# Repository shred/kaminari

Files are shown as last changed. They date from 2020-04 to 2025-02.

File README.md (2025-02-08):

# Kaminari

This is an ESP8266 and AS3935 based Franklin Lightning Detector. It connects to a WiFi network, and offers a JSON web service for detected lightnings.

**WARNING: This project is for educational purposes only.** This is just a toy. It is not intended to be used as an early warning indicator for lightning related storms. It does not guarantee accuracy or predict exact strike locations. It it not a replacement for a professional lightning detector. Again: **This is just a toy.**

## Features

* Small size and low power consumption
* Can be read out and configured via HTTP web service and JSON
* Lightnings can be reported via MQTT
* Optional RGBW LED for showing the system status and detected lightnings
* Self-calibrating detector
* Permanent automatic noise floor level adjustment

## Building and Installation

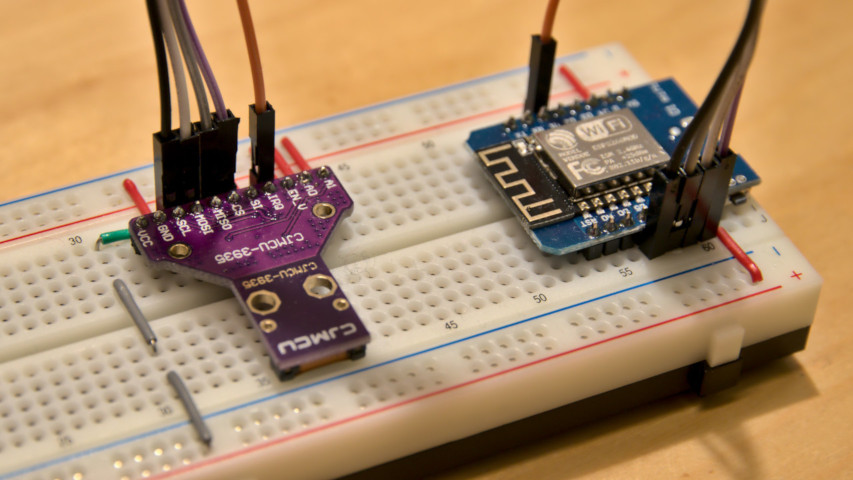
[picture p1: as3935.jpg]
Prototype


### Hardware

You need:

- An **ESP8266** module. You can use any brand, as long as it provides a regulated 3.3 V power source, and exposes the SPI interface and GPIO 5.
- An **AS3935** Franklin Lightning Detector module. Again, no special brand is required, as long as the SPI interface is exposed.

The lightning detector is connected like this:

- Vcc → 3.3 V power output of the ESP board
- SCL → CLK (IO14)
- MOSI → MOSI (IO13)
- MISO → MISO (IO12)
- CS → CS (IO15)
- IRQ → IO5

All other terminals of the detector are connected to GND of the ESP board.

Optionally, a single **SK6812** RGBW LED can be added as a status LED. It is must be powered by 5 V, and its data input is directly connected to IO4.

No other components are required.

To fully understand the functionality of the lightning detector, please read the [AS3935 datasheet](https://www.sciosense.com/wp-content/uploads/documents/AS3935-Data-Sheet.pdf).

### Important Notes

- The ESP8266's WiFi is disturbing the AS3935 detector, and reducing the quality of lightning detection up to a point where lightnings cannot be detected at all. **Make sure there is sufficient space between both boards!** There should be at least 10 cm between the WiFi antenna and the detector coil. The more space, the better.

* Some manufacturers of the lightning detector print a calibration value on the package. As Kaminari calibrates the detector automatically, the calibration value is not needed.

* Some AS3935 boards are equipped with non-standard parts in the antenna RC, and thus cannot be tuned to the recommended frequency of 500 kHz. If you're lucky, it is still within the required tolerance of ±3.5%. Those boards can be used, but may give inferior results. It is not a fault of Kaminari if the exact frequency is missed. (I got multiple reports about CJMCU boards having this issue, and can confirm it with my own board of this brand.)

### Firmware

To build the firmware, you need to install the [Arduino IDE](https://www.arduino.cc/en/Main/Software). After installation, just open the `kaminari.ino` file.

### Dependencies

Please make sure these libraries are installed in the Library Manager of the Arduino IDE:

* [Arduino on ESP8266](https://github.com/esp8266/Arduino) (via Board Manager)
* [ArduinoJson](https://arduinojson.org/)
* [Adafruit NeoPixel](https://github.com/adafruit/Adafruit_NeoPixel)
* [EEPROM_Rotate](https://github.com/xoseperez/eeprom_rotate)
* [PubSubClient](https://github.com/knolleary/pubsubclient)

### Configuration

Before you build the project for the first time, please copy the `myWiFi.h.example` file to `myWiFi.h`, and adapt it to your needs:

- `MY_SSID`: The SSID of your WLAN to connect to
- `MY_PSK`: The password of your WLAN
- `MY_APIKEY`: Your API key for endpoint calls that change the state of the detector. You can set a random, password-like word here.
- `MY_MDNS_NAME`: Your preferred mDNS name. Just use the default value `kaminari` if you don't know what to use here.

To send lightning events via MQTT, these additional options need to be configured:

- `MY_MQTT_ENABLED`: This line needs to be commented in to activate MQTT support. MQTT is disabled by default.
- `MY_MQTT_SERVER_HOST`: Host name of the MQTT server.
- `MY_MQTT_SERVER_PORT`: Port of the MQTT server (default is 1883).
- `MY_MQTT_USER`: MQTT authentication user name
- `MY_MQTT_PASSWORD`: MQTT authentication password
- `MY_MQTT_TOPIC`: MQTT topic to be used
- `MY_MQTT_RETAIN`: `true` if messages shall be retained. Default is `false`.

### Installation

Now you can build the project in ArduinoIDE.

After that, connect your ESP8266 via USB. In the _Tools_ menu, please set all parameters so you can upload the sketch to your ESP8266. The settings depend on the brand of your module and on your computer's operating system, so there are no generic settings that can be recommended here.

When everything is completed, upload the sketch to your module. That's all.

You can open the _Serial Monitor_ to read some debug output of Kaminari as it starts up. You will find the WiFi status, the IP address, and the calibration results there.

### Connection

There is a small web server running in Kaminari. You can connect to it by pointing your browser to the IP address (e.g. http://192.168.1.23/status).

Kaminari uses mDNS. If your operating system supports it, you can also connect to the sensor via http://kaminari.local/status (or whatever mDNS name you have used in your `myWiFi.h` file).

## Endpoints

Kaminari offers a set of endpoints. Some endpoints are read-only. Other endpoints change the state of the detector, and thus require the API key to be passed in via `X-API-Key` header or `api_key` URL parameter. For the sake of simplicity, all requests are `GET` requests, even those that change the state of the detector.

### `/status`

Returns the current status of the detector as JSON structure. This is an example result:

```
{
    "lightnings": [
        {
            "age": 34,
            "distance": 12,
            "energy": 38123
        }
    ],
    "distance": null,
    "energy": 0,
    "noiseFloorLevel": 146,
    "disturbersPerMinute": 81,
    "watchdogThreshold": 1,
    "wifiSignalStrength": -55
}
```

This is the meaning of the individual properties:

- `lightnings`: An array of detected lightnings. It contains the `age` of the event (in seconds), the estimated `distance` of the lightning (in kilometres) and the lightning `energy` (no physical unit). Kaminari stores up to 64 lightning events, and returns them in antichronological order. When a 65th event is recorded, the oldest record will automatically be removed from the list. This array is empty if no lightnings have been detected yet.
- `distance`: General distance of the storm, in kilometres. `null` means that the storm is out of range, while `1` means that the storm is overhead. May also contain values caused by disturbers. For debugging purposes only, may be removed in a future version.
- `energy`: General energy of detected lightnings, with no physical unit. May also contain values caused by disturbers. For debugging purposes only, may be removed in a future version.
- `noiseFloorLevel`: Current noise floor level, in µVrms. Kaminari raises or lowers the level automatically, depending on the level of environment radio noises.
- `disturbersPerMinute`: Number of detected disturbers per minute. The value should be as low as possible for best results. Higher values mean that the detector is receiving a lot of disturbing radio noises.
- `watchdogThreshold`: Current watchdog threshold. Range is between 0 and 10. Higher values mean lower sensibility against disturbers, but also lower sensibility against very far lightning events.
- `wifiSignalStrength`: Current WiFi received signal strength, in dBm.

### `/settings`

Returns the current settings of the detector as JSON structure, for example:

```
{
    "tuning": 500135,
    "noiseFloorLevel": 146,
    "outdoorMode": false,
    "watchdogThreshold": 2,
    "minimumNumberOfLightning": 1,
    "spikeRejection": 2,
    "statusLed": true,
    "blueBrightness": 48,
    "disturberBrightness": 100
}
```

- `tuning`: The tuning of the internal antenna, in Hz. Should be around 500 kHz, with a tolerance of ±3.5%.
- `noiseFloorLevel`: Current noise floor level, in µVrms.
- `outdoorMode`: `true` if the detector is switched to outdoor mode. In outdoor mode, a higher noise floor level voltage is used for suppressing disturbers. If the LED is blinking blue, you can try to enable the outdoor mode to make the device less sensitive for disturbers.
- `watchdogThreshold`: Current watchdog threshold, see AS3935 datasheet.
- `minimumNumberOfLightning`: Minimum number of lightnings until a lightning detected event is triggered.
- `spikeRejection`: Current spike rejection, see AS3935 datasheet.
- `statusLed`: If `true`, the status LED displays signal quality and detected lightnings. If `false`, the status LED will only display important system states (WLAN disconnected, calibration in progress) and is turned off otherwise.
- `blueBrightness`: Maximum brightness of the blue LED indicating the noise floor level.
- `disturberBrightness`: Brightness of the LED when a disturber is detected.

### `/update`

This endpoint permits to change the settings. Settings to be changed are passed as URL parameter:

- `outdoorMode`: Enable or disable the outdoor mode.
- `watchdogThreshold`: Watchdog threshold, between 0 and 10, see AS3935 datasheet. Higher numbers give better robustness against disturber signals, but a lower lightning detection rate.
- `minimumNumberOfLightning`: Minimum number of lightnings until a lightning detected event is triggered. Only 1, 5, 9, and 16 are permitted, other values will be ignored.
- `spikeRejection`: Spike rejection, between 0 and 11, see AS3935 datasheet. Higher numbers give better robustness against disturber signals, but a lower lightning detection rate.
- `statusLed`: Change the status LED operation.
- `blueBrightness`: Maximum brightness of the blue LED indicating the noise floor level, between 0 and 255. 0 turns the constant blue light off, while lightnings, disturbers, and system states are still indicated.
- `disturberBrightness`: Brightness of the LED when a disturber is detected, between 0 and 255. 0 to turn off disturber indication.

The changes are permanently stored and will still be effective after Kaminari had been powered off and on.

Other settings are managed by Kaminari and cannot be changed externally.

The API key is required for this call.

### `/calibrate`

This endpoint forces a new calibration of the internal oscillators. The calibration takes approximately 5 seconds. The calibrated antenna tuning is returned. It should be around 500 kHz.

The API key is required for this call.

### `/clear`

This endpoint clears the list of detected lightnings, the age of the last detected disturber, and the counter of disturbers per minute.

The API key is required for this call.

### `/reset`

This endpoint resets the detector chip. May be useful if the detector cracks up or behaves strangely. This call also includes a calibration and resetting the statistics.

The API key is required for this call.

## Status LED

An optional RGBW LED is showing the current status of the device:

- **constant yellow**: The antenna is being calibrated. This takes approximately 5 seconds.
- **blinking red**: The WLAN connection is lost, and the device is currently trying to reconnect.
- **constant blue**: The device is in normal operation mode. The brightness of the blue color is an indicator for the current noise floor level. Darker blue indicates a lower noise floor level, which should be preferred. The maximum brightness can be changed via the `/update` endpoint.
- **blinking blue**: The maximum noise floor level has been reached. Background noise is too high. You should find a different place for your detector, or enable the outdoor mode. Try to keep it away from electronic devices, especially bluetooth devices, mobile phones or microwaves.
- **white flash**: A lightning has been detected.
- **fading red, yellow or green tints**: Indicates the estimated distance (color) and the intensity of the lightning (brightness). Green indicates that the storm is about 40 km away. Red indicates that the storm is overhead. The hue of other colors represent distances between.
- **fading pink/red tints** without prior white flash: A disturber has been detected.

## MQTT events

If MQTT support is enabled, Kaminari will publish a message on every detected lightning event. The payload is a JSON structure:

```
{
    "energy": 0,
    "distance": null,
    "tuning": 500135,
    "noiseFloorLevel": 146,
    "disturbersPerMinute": 2,
    "watchdogThreshold": 1,
    "wifiSignalStrength": -55
}
```

This is the meaning of the individual properties:

- `energy`: Estimated energy of the detected lightning (no physical unit). May be `null` if a disturber was detected.
- `distance`: Estimated distance of the lightning, in kilometres. May be `null` if the storm is out of range. `1` means that the storm is overhead.
- `tuning`: The tuning of the internal antenna, in Hz. Should be around 500 kHz, with a tolerance of ±3.5%.
- `noiseFloorLevel`: Current noise floor level, in µVrms. Kaminari raises or lowers the level automatically, depending on the level of environment radio noises. This value gives a hint about signal quality.
- `disturbersPerMinute`: Number of detected disturbers per minute. The value should be as low as possible for best results. Higher values mean that the detector is receiving a lot of disturbing radio noises. This value gives a hint about signal quality.
- `watchdogThreshold`: Current watchdog threshold. Range is between 0 and 10. Higher values mean lower sensibility against disturbers, but also lower sensibility against very far lightning events. This value gives a hint about signal quality.
- `wifiSignalStrength`: Current WiFi received signal strength, in dBm.

## Data Recording

You can frequently poll the `/status` endpoint for lightnings and other sensor values. This can be done either manually or automated.

[Geordi](https://geordi.shredzone.org) is a tool that frequently polls the status and stores the samples in a Postgresql database. It supports Kaminari directly. [Grafana](https://grafana.com/) can be used for visualising the results.

## FAQ

- **Does this detector warn me in time if…**

  No.

  Seriously, this is just a toy, and only meant for experimenting and having fun. Never trust your life and other valuable stuff on it.

- **How can I test it?**

  The manufacturer sells a [demo kit](https://www.sciosense.com/products/wireless-sensor-nodes/demo-kit-for-as3935/) that also contains a "lightning emulator", but the least expensive way is to wait for an actual thunderstorm.

  You can also increase sensitivity by reducing `watchdogThreshold` and `spikeRejection`, and then try to simulate lightnings by switching a light switch. I could also simulate lightnings by using a bluetooth mouse or a mobile phone close to the sensor.

- **I get a lot of false lightning events.**

  You can experiment with the `watchdogThreshold`, `spikeRejection` and `minimumNumberOfLightning` settings. There is not much more that can be done though.

- **Lightnings are not detected.**

  Your detector might be located in a place with too many radio noises. Try to find a different place, far away from radio sources (like smartphones or bluetooth devices). You can also try to reduce `watchdogThreshold`, `spikeRejection` or `minimumNumberOfLightning`.

  The ESP8266 WiFi is a strong disturber. Try to give more space between the WiFi antenna and the detector coil, in order to reduce disturbers.

  Lightnings are only detected in a radius of up to 40 km. However, lightnings are poorer detected with increasing distance.

- **I get a lot of disturber indications.**

  Try to find a place with less radio disturbers, and experiment with the `watchdogThreshold` and `spikeRejection` settings. If the disturber indications are annoying you, you can also set `disturberBrightness` to 0.

- **I'd to write my own lightning detector firmware.**

  The `AS3935.cpp` and `AS3935.h` files in this project provide a generic driver class for the AS3935 sensor chip. You can use it in your own project, as long as you won't remove the copyright header and respect the terms of our license.

- **Are kits or assembled devices available?**

  No, at least not that I am aware of.

## Contribute

* Fork the [Source code at Codeberg](https://codeberg.org/shred/kaminari). Feel free to send pull requests.
* Found a bug? [File a bug report!](https://codeberg.org/shred/kaminari/issues) However, please don't file complaints about a poor accuracy or false detections. Remember that this is a toy and not a professional lightning detector.

## License

_Kaminari_ is open source software. The source code is distributed under the terms of [GNU General Public License (GPLv3+)](https://www.gnu.org/licenses/gpl-3.0.en.html).

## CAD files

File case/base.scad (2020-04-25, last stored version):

/*
 * Kaminari
 *
 * Copyright (C) 2020 Richard "Shred" Körber
 *   https://github.com/shred/kaminari
 *
 * This program is free software: you can redistribute it and/or modify
 * it under the terms of the GNU General Public License as published by
 * the Free Software Foundation, either version 3 of the License, or
 * (at your option) any later version.
 *
 * This program is distributed in the hope that it will be useful,
 * but WITHOUT ANY WARRANTY; without even the implied warranty of
 * MERCHANTABILITY or FITNESS FOR A PARTICULAR PURPOSE.  See the
 * GNU General Public License for more details.
 */

use <kaminari.scad>
lower();

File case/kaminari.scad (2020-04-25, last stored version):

/*
 * Kaminari
 *
 * Copyright (C) 2020 Richard "Shred" Körber
 *   https://github.com/shred/kaminari
 *
 * This program is free software: you can redistribute it and/or modify
 * it under the terms of the GNU General Public License as published by
 * the Free Software Foundation, either version 3 of the License, or
 * (at your option) any later version.
 *
 * This program is distributed in the hope that it will be useful,
 * but WITHOUT ANY WARRANTY; without even the implied warranty of
 * MERCHANTABILITY or FITNESS FOR A PARTICULAR PURPOSE.  See the
 * GNU General Public License for more details.
 */

basesize = 60;
tipheight = 40;
wall = 1.5;

mount_distance = 40;
mount_diameter = 7;
mount_screw_diameter = 3;
mount_screw_length = 10;
mount_head_depth = 2;
mount_head_diam = 5.8;

usb_width = 11;
usb_height = 7;

module pyramid(size) {
    height = size/2 * sqrt(3);
    polyhedron(
        points=[
            [ size/2,  size/2, 0     ],
            [ size/2, -size/2, 0     ],
            [-size/2, -size/2, 0     ],
            [-size/2,  size/2, 0     ],
            [      0,       0, height]
        ],
        faces=[
            [0,1,4],
            [1,2,4],
            [2,3,4],
            [3,0,4],
            [1,0,3], [2,1,3]
        ]
    );
}

module led() {
    color("silver") cylinder(d=10, h=1.3);
    color("white") translate([0, 0, 1.3 + (2.8-1.3)/2]) cube([5, 5, 2.8-1.3], center=true);
}

module detector() {
    translate([-28.4/2, -30.1/2, 0]) {
        color("purple") difference() {
            linear_extrude(height=2.4) {
                polygon([[0, 0], [28.4, 0], [28.4, 9.2], [20.25, 15.1], [20.25, 30.1], [8.15, 30.1], [8.15, 15.1], [0, 9.2], [0, 0]]);
            }
            translate([ 8.15 + 3/2 + 1, 21, -1]) cylinder(d=2.95, h=4);
            translate([20.25 - 3/2 - 1, 21, -1]) cylinder(d=2.95, h=4);
        }
        color("darkslategrey") translate([8.15, 30.1-3.2, 2.4]) cube([12.1, 3.2, 1.8]);
        color("black") translate([0, 0, -1]) cube([28.4, 2.5, 11.4]);
    }
}

module mcu() {
    translate([-25.8/2, -34/2, 8]) {
        color("royalblue") cube([25.8, 34, 1.3]);
        color("silver") translate([(25.8-12)/2, 12, 1.3]) cube([12, 15, 3.2]);
        color("black") translate([0, 0, -2]) cube([25.8, 28, 2]);
        color("silver") translate([(25.8-7.8)/2, -0.1, -1.9]) cube([7.8, 7, 1.9]);
        color("black") translate([0, 7.4, -8]) cube([2.5, 21, 8]);
        color("black") translate([25.8-2.5, 7.4, -8]) cube([2.5, 21, 8]);
    }
}

module stripe(dim) {
    translate([dim[1]/2, 0, 0]) cylinder(d=dim[1], h=dim[2]);
    translate([dim[1]/2, -dim[1]/2, 0]) cube([dim[0] - dim[1], dim[1], dim[2]]);
    translate([dim[0] - dim[1]/2, 0, 0]) cylinder(d=dim[1], h=dim[2]);
}

module mountBar(height) {
    difference() {
        cylinder(d = mount_diameter, h = height);
        cylinder(d = mount_screw_diameter, h = mount_screw_length, $fn = 5);
    }
}

module upper() {
    difference() {
        intersection() {
            pyramid(basesize);
            ph =  basesize/2 * sqrt(3);
            translate([0, 0, ph/2 - 1]) cube([basesize, basesize, ph], center=true);
        }
        pyramid(basesize - wall*2);
        translate([(-usb_width)/2, (usb_height-7)/2-20, 8]) rotate([90, 0, 0]) stripe([usb_width, usb_height, 10]);
    }

    intersection() {
        union() {
            translate([ mount_distance/2,  mount_distance/2, wall*2]) mountBar(basesize);
            translate([ mount_distance/2, -mount_distance/2, wall*2]) mountBar(basesize);
            translate([-mount_distance/2,  mount_distance/2, wall*2]) mountBar(basesize);
            translate([-mount_distance/2, -mount_distance/2, wall*2]) mountBar(basesize);
        }
        pyramid(basesize);
    }
}

module middle_led() {
    difference() {
        translate([-10, -10, 0]) cube([20, 20, 3.5]);
        translate([0, 0, 1]) cylinder(d=10.5, h=4);
        rotate([0, 0, -180]) translate([-4.3, -2, -.1]) stripe([8.6, 5, 3.2]);
    }
}

module lower_detector() {
    translate([-11.5, -basesize/2 - 15, 0]) cube([4, basesize, 20]);
}

module middle() {
    intersection() {
        difference() {
            union() {
                // LED holder
                translate([0, 0, 35]) middle_led();
                translate([-basesize/2, -basesize/2, 22]) cube([basesize, 30, 13]);
            }
            translate([ 3.5, -6, 21.9]) cylinder(d=3, h=12, $fn=5);
            translate([-3.5, -6, 21.9]) cylinder(d=3, h=12, $fn=5);
        }
        pyramid(basesize - wall*2);
    }
}

module basePlate() {
    difference() {
        union() {
            translate([0, 0, wall/2]) cube([basesize, basesize, wall], center=true);
            translate([ mount_distance/2,  mount_distance/2, 0]) cylinder(d = mount_diameter, h = wall*2);
            translate([ mount_distance/2, -mount_distance/2, 0]) cylinder(d = mount_diameter, h = wall*2);
            translate([-mount_distance/2,  mount_distance/2, 0]) cylinder(d = mount_diameter, h = wall*2);
            translate([-mount_distance/2, -mount_distance/2, 0]) cylinder(d = mount_diameter, h = wall*2);
        }

        translate([ mount_distance/2,  mount_distance/2, 0]) cylinder(d = mount_screw_diameter, h = mount_screw_length);
        translate([ mount_distance/2, -mount_distance/2, 0]) cylinder(d = mount_screw_diameter, h = mount_screw_length);
        translate([-mount_distance/2,  mount_distance/2, 0]) cylinder(d = mount_screw_diameter, h = mount_screw_length);
        translate([-mount_distance/2, -mount_distance/2, 0]) cylinder(d = mount_screw_diameter, h = mount_screw_length);

        translate([ mount_distance/2,  mount_distance/2, 0]) cylinder(d1 = mount_head_diam, d2 = mount_screw_diameter, h = mount_head_depth);
        translate([ mount_distance/2, -mount_distance/2, 0]) cylinder(d1 = mount_head_diam, d2 = mount_screw_diameter, h = mount_head_depth);
        translate([-mount_distance/2,  mount_distance/2, 0]) cylinder(d1 = mount_head_diam, d2 = mount_screw_diameter, h = mount_head_depth);
        translate([-mount_distance/2, -mount_distance/2, 0]) cylinder(d1 = mount_head_diam, d2 = mount_screw_diameter, h = mount_head_depth);

        for (x = [-8 : 2 : 8]) {
            translate([x, 0, wall/2-1]) cube([1, 25, wall+3], center=true);
        }
    }
}

module lower() {
    intersection() {
        union() {
            basePlate();
            translate([-16, -basesize, 0]) cube([3, basesize, 22]);
            translate([16-3, -basesize, 0]) cube([3, basesize, 22]);

            difference() {
                union() {
                    translate([-13.5, -28, 0]) cube([27, 10, 5.7]);
                    translate([-13.5, -26.2, 0]) cube([27, 3, 13]);
                }
                translate([(-usb_width)/2, (usb_height-7)/2-23.19, 8]) rotate([90, 0, 0]) stripe([usb_width, usb_height, 10]);
            }

            difference() {
                union() {
                    translate([12.5, 11, 3]) cube([7, 10, 8], center=true);
                    translate([-12.5, 11, 3]) cube([7, 10, 8], center=true);
                }
                translate([0, -6.1, 7]) cube([25.8, 34, 2.6], center=true);
            }
        }
        pyramid(basesize - wall*2);
    }
}

module middle2() {
    intersection() {
        difference() {
            union() {
                translate([0, 9, 13.3]) cube([32, 6, 12.6], center=true);
                translate([-16, 0, wall]) cube([3, 6, 19.6-wall]);
                translate([16-3, 0, wall]) cube([3, 6, 19.6-wall]);
                translate([-16, 0, wall]) cube([3, 4, 30-wall]);
                translate([16-3, 0, wall]) cube([3, 4, 30-wall]);
            }
            translate([0, 9, 20]) cube([14, 7, 6], center=true);
            translate([0, 9, 10]) cube([18, 7, 6], center=true);
        }
        pyramid(basesize - wall*2);
    }
}

if (!$preview) {
    upper();
}
middle();
middle2();
lower();

translate([0, 0, 22]) rotate([0, 180, 180]) detector();
translate([0, -6.2, 15]) rotate([0, 180, 0]) mcu();
translate([0, 0, 36]) led();

$fn=90;

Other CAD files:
case/clip.scad
case/holder.scad
case/top.scad

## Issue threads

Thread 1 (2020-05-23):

Calibrated antenna frequency 0 Hz

HaViGit, 2020-05-23:
First of all, thank you for sharing this project. I followed your instructions and the sketch runs. Unfortunately, the serial monitor reports the calibrated antenna frequency is 0 Hz and that seems wrong to me. Below the relevant Serial Monitor output. Can you advise me what to do?

_Calibrating antenna...
Calibrated antenna frequency: 0 Hz
MDNS responder started
Server is listening on port 80
Connected to TS123
IP address: 192.168.2.39
MAC: 80:7D:3A:66:AB:EE_

shred, 2020-05-23:
The only reason for 0 Hz after calibration is a problem with the interrupt.

- Make sure the IRQ out of the AS3935 is connected to the correct port of your ESP. It is supposed to be the GPIO5 pin. On my ESP board this pin is labeled "D1", but it can be different on your board. You can also use any other free port, but you need to adapt the `AS_INT` constant at the top of `kaminari.ino` accordingly.
- If you have a scope, make sure there is a signal on the IRQ line during calibration.
- If you don't use an ESP8266 board, maybe your board is not able to handle interrupts at all, or cannot handle interrupts on the GPIO5 pin.

What ESP board are you using?

HaViGit, 2020-05-23:
Thanks for your fast respond! The board I use is a Wemos D1 Mini (not the pro),  these are my definitions in the sketch:

#define SPI_CS   15        // IO15 (D8)
#define SPI_MOSI 13     // IO13 (D7)
#define SPI_MISO 12     // IO12 (D6)
#define SPI_SCK  14      // IO14 (D5)
#define AS_INT    5       // IO5  (D1)
#define NEOPIXEL  4     // IO4  (D2)

Can you tell me how to connect the AS3935 sensor when using above definitions and the Wemos board? As you know, these are the pins:

Vcc → 3.3 V
GND → GND
SCL →
MOSI →
MISO →
CS →
SI →
IRQ →
EN_V →
A0 →
A1 →

shred, 2020-05-23:
The Wemos D1 Mini seems to be the same type as the board I am using. The correct wiring is:

Vcc → 3.3 V
GND → GND
SCL → D5
MOSI → D7
MISO → D6
CS → D8
SI → GND
IRQ → D1
EN_V → GND
A0 → GND
A1 → GND

Be careful with the wiring for MISO and MOSI. The correct wire order on the ESP side is D5-**D7-D6**-D8, not D5-**D6-D7**-D8. I had them mixed up on my first wiring attempt.

Thinking about your problem again, it's also possible that the ESP cannot talk to your AS3935 at all. Anyway, my bet is on a wiring issue.

HaViGit, 2020-05-23:
After re-wiring as described and double checking, the calibrated antenna frequency is still reported as 0 Hz. During calibration my scope shows a signal on the IRQ line (D1). Although I am using a Wemos D1 mini like you did, do you think this board (sometimes) cannot talk to the AS3935 board?

Also not sure if this AS3935 board is a good choice, there are many issues reported on the internet, especially about calibration. So I now consider to order the SEN0290 sensor from DFRobot.

shred, 2020-05-23:
I have added a few diagnostics logs in commit 49baecdd. It should tell you whether the AS board is not visible, or if the IRQ signal is just missing.

"No AS3935 was detected. Please check your wiring!" -> ESP cannot talk to the AS3935. (Bad SPI wiring?)
"No interrupt detected during calibration. Please check your wiring!" -> ESP does not receive interrupts. (Bad IRQ wiring?)

You are right, calibrating the AS3935 is difficult. However, the Kaminari firmware should do most of the calibration work for you.

HaViGit, 2020-05-23:
To be sure it was not the Wemos D1 Mini I have replaced it with another one, a Pro version. Running your latest sketch this it the serial monitor output:

_Calibrating antenna...
No interrupt detected during calibration. Please check your wiring!
Warning: calibrated frequency is out of tolerance range.
Calibrated antenna frequency: 0 Hz
Server is listening on port 80_

Wiring is okay, board should not be the problem so only the AS3935 sensor seems to cause the issue. Especially since the sensor can only be tested during a thunderstorm, I must be sure that it is reliable. I think this sensor board is not and I have lost confidence, partly because of the many issues on the internet. I am going to order the sensor from DFRobot so I have to be patient.

Anyway thanks for helping Richard!

shred, 2020-05-23:
I'm sorry that I couldn't help you, but I'm out of clues. You said there is a signal on the IRQ line, but still the Wemos does not receive any interrupts. Maybe the Wemos ESP firmware is just different to the firmware on my ESP?

But if you need a reliable solution, this might be the wrong project for you anyway. It is just meant for experimental purposes.

I'm closing this issue. Feel free to reopen it if you found something.

Closed 2020-05-23.

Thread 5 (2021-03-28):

add MQTT support?

DarKOrange75, 2021-03-28:
Hi, thank you for your nice work! I would like to integrate your sensor into my Home Assistant setup. Could you please add MQTT support when you have time? This would be awesome. Thank you!

shred, 2021-03-28:
Yes! This is actually on top of my To-Do list for this project. I will keep this issue open as a reminder and for notifications.

shred, 2021-03-28:
MQTT support is added in commit 595fe3a8. It is not thoroughly tested, so I'd appreciate your feedback.

DarKOrange75, 2021-03-29:
Awesome, I'll test it as soon as I can!

DarKOrange75, 2021-03-29:
The serial monitor says that it is connected to MQTT server but nothing is published:
10:43:13.377 -> Calibrated antenna frequency: 499072 Hz
10:43:13.516 -> MDNS responder started
10:43:13.516 -> Server is listening on port 80
10:43:16.535 -> Connected to DKON2
10:43:16.535 -> IP address: 192.168.1.19
10:43:16.535 -> MAC: EC:FA:BC:6E:18:BA
10:43:16.535 -> Successfully connected to MQTT server

The status shows that the sensor was triggered though:

{"lightnings":

[{"age":186,"energy":165851,"distance":6}],"distance":6,"energy":0,"noiseFloorLevel":78,"disturbersPerMinute":7,"watchdogThreshold":0}

DarKOrange75, 2021-03-29:
is this normal?

if (client.connect("kaminari", MY_MQTT_USER, MY_MQTT_PASSWORD))

shred, 2021-03-29:
Yes... You are supposed to set the correct MQTT credentials in your `myWiFi.h` as `MY_MQTT_USER` and `MY_MQTT_PASSWORD`. If you don't need to authenticate, set both to `NULL`.

I was able to receive lightning events in Mosquitto, so it should work in general. Errors while publishing were not logged, so if there was an error, it would go unnoticed. I've added error logging in commit be4ef1d6. The error codes are [documented here](https://pubsubclient.knolleary.net/api#state). Can you check if you get an error instead of a lightning event message?

DarKOrange75, 2021-03-29:
I meant is "kaminari" normal or is it a leftover of your tests in the code ?

shred, 2021-03-29:
It's the client ID. But you are right, it should be configurable as well.

DarKOrange75, 2021-03-29:
OK that's weird, it work only once, I got a notification in mosquito, deleted it and now nothing is published anymore...

DarKOrange75, 2021-03-29:
After some tests, nothing is wrong with the MQQT connection, it looks like this condition is preventing the publishing of the lightning alert:

if (!detector.getLastLightningDetection(0, ledLightning))

shred, 2021-03-31:
Strange, I could get lightning events that way. I will have a look at it in the next days.

DarKOrange75, 2021-05-14:
No problem Richard

shred, 2021-06-06:
Hopefully @gubiq's patch has fixed the MQTT status problem. If not, feel free to reopen this issue. But I will also keep on looking into this issue while I try to get my hardware fixed. (It still does not detect any lightnings any more, not even false positives.)

Closed 2021-06-06.

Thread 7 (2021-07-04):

Help with settings

ve3sjk, 2021-07-04:
Could you provide and example on how to change settings via the webpage?

shred, 2021-07-04:
Sure... To change the settings, you invoke the `/update` endpoint and provide as GET parameters what you want to change. You also need to provide an `api_key` parameter with the API key you defined in your `myWiFi.h` file.

For example, to turn off the LED through a browser, you can invoke:

```
http://kaminari.localdomain/update?statusLed=false&api_key=MySeCrEtApIkEy
```

(Replace `kaminari.localdomain` with your Kaminari's host name or IP address, and set the proper API key.)

You can also provide the API key as `X-API-Key` header, e.g.:

```
curl -H 'X-API-Key: MySeCrEtApIkEy' 'http://kaminari.localdomain/update?statusLed=false'
```

ve3sjk, 2021-07-08:
Thanks for the response that was the info i was looking for, can i ask if you have seen any real lightning detected using your unit. I have tried 2 different boards in this setup now, in both cases i get perfect tuning at 500k but it does not trigger on lightning events, i have had storms overhead last night and 5 minutes ago with plenty of lightning and the system did not see any of the strikes at all.

shred, 2021-07-09:
I'm experimenting with my AS3935 for more than a year now, and I'm finally making a bit of progress. What I could find out so far:

* It's crucial to have enough space between the AS3935 and the ESP board, as the ESP's WiFi antenna is a strong disturber. It seems that 10cm (4 inch) is sufficient.
* A perfect 500kHz tuning seems to be important. After I replaced the wrong capacitors on my CJMCU AS3935, the result seemed to be better.
* My initial idea to auto-adjust the watchdog level turned out to confuse the AS3935 and cause a lot of false positives. I got much better results after setting `autoWatchdogMode` to `false` and `watchdogThreshold` to a fixed value (currently `3` here). I'm about to remove the watchdog auto-adjustment from the code because of that, or at least disable it by default.
* The number of disturbers per minute should be almost 0 on fair weather. If it's higher, give more space between the sensor and the ESP, or find a better place for the sensor with less disturbers. (If there is a thunderstorm approaching, the number of disturbers per minute will still rise, but that seems to be normal.)

With this setup, I only get a few false positives per day. If a thunderstorm approaches, I get many lightning events now. Together with the raising number of disturbers per minute, it's indeed possible to check if a thunderstorm is approaching.

However it's not like that the detector detects every lightning that I can see outside. The distance estimation is also totally useless at the moment, because almost all lightnings are reported as "right overhead".

I keep on experimenting, but it's in the nature of this project that the progress is very slow.

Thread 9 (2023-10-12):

Can I use I2C interface?

diegostf, 2023-10-12:
Hi,
  I'm using AS3935 with ESP32-S2, but I get a lot of wrong information from the registers when using 3,3V. I read some reports of problems with the I2C interface and saw many projects using SPI.
Did you have problems using I2C and that's why you chose SPI?
SPI needs a lot of cables and this is a problem when the sensor is far from the ESP.

shred, 2023-10-13:
Hi diegostf!

No, I started with SPI right away, mainly because all examples I could find were using SPI. It also turned out to be very stable, so I saw no reason to switch to I²C.

I²C is also much slower than SPI, and requires an additional external pull-up resistor on the SCL line.

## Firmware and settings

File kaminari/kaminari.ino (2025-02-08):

/*
 * Kaminari
 *
 * Copyright (C) 2020 Richard "Shred" Körber
 *   https://codeberg.org/shred/kaminari
 *
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
 * This program is distributed in the hope that it will be useful,
 * but WITHOUT ANY WARRANTY; without even the implied warranty of
 * MERCHANTABILITY or FITNESS FOR A PARTICULAR PURPOSE.  See the
 * GNU General Public License for more details.
 */

#include <SPI.h>
#include <ArduinoJson.h>
#include <ESP8266WiFi.h>
#include <WiFiClient.h>
#include <ESP8266WebServer.h>
#include <ESP8266mDNS.h>
#include <Adafruit_NeoPixel.h>
#include <PubSubClient.h>

#include "AS3935.h"
#include "Config.h"
#include "myWiFi.h"

#define SPI_CS   15     // IO15 (D8)
#define SPI_MOSI 13     // IO13 (D7)
#define SPI_MISO 12     // IO12 (D6)
#define SPI_SCK  14     // IO14 (D5)
#define AS_INT    5     // IO5  (D1)
#define NEOPIXEL  4     // IO4  (D2)

#define PORT 80

#define COLOR_CONNECTING   0x00800000
#define COLOR_CALIBRATING  0x00404000
#define COLOR_BLACK        0x00000000

#define DISTANCE_ANIMATION_TIME 5000
#define ENERGY_ANIMATION_TIME    500
#define DISTURBER_ANIMATION_TIME 1000

ConfigManager cfgMgr;
ESP8266WebServer server(PORT);
AS3935 detector(SPI_CS, AS_INT);
Adafruit_NeoPixel neopixel(1, NEOPIXEL, NEO_GRBW + NEO_KHZ800);
WiFiClient wifiClient;
PubSubClient client(MY_MQTT_SERVER_HOST, MY_MQTT_SERVER_PORT, wifiClient);
WiFiEventHandler connectedEventHandler, gotIpEventHandler, disconnectedEventHandler;

unsigned long beforeAnimation = millis();
unsigned long beforeMqttConnection = millis();
bool connected = false;
unsigned int currentColor = 0;
Lightning ledLightning;

inline static unsigned long timeDifference(unsigned long now, unsigned long past) {
    // This is actually safe from millis() overflow because all types are unsigned long!
    return past > 0 ? (now - past) : 0;
}

void sendJsonResponse(ArduinoJson::JsonDocument &doc, int status = 200) {
    String json;
    serializeJson(doc, json);
    server.send(status, "application/json", json);
}

bool authenticated() {
    if (server.header("X-API-Key") == MY_APIKEY) {
        return true;
    }
    if (server.arg("api_key") == MY_APIKEY) {
        return true;
    }
    server.send(403);
    return false;
}

void handleStatus() {
    DynamicJsonDocument doc(8192);

    unsigned long now = millis();

    JsonArray la = doc.createNestedArray("lightnings");
    Lightning lightning;
    for (int ix = 0; ; ix++) {
        if (!detector.getLastLightningDetection(ix, lightning)) {
            break;
        }
        StaticJsonDocument<200> subdoc;
        subdoc["age"] = timeDifference(now, lightning.time) / 1000;
        subdoc["energy"] = lightning.energy;
        if (lightning.distance < 0x3F) {
            subdoc["distance"] = lightning.distance;
        } else {
            subdoc["distance"] = (char*) NULL;
        }
        la.add(subdoc);
    }

    unsigned int distance = detector.getEstimatedDistance();
    if (distance < 0x3F) {
        doc["distance"] = distance;
    } else {
        doc["distance"] = (char*) NULL;
    }

    doc["energy"] = detector.getEnergy();
    doc["noiseFloorLevel"] = detector.getNoiseFloorLevel();
    doc["disturbersPerMinute"] = detector.getDisturbersPerMinute();
    doc["watchdogThreshold"] = detector.getWatchdogThreshold();
    doc["wifiSignalStrength"] = WiFi.RSSI();

    sendJsonResponse(doc);
}

void handleSettings() {
    DynamicJsonDocument doc(1024);
    doc["tuning"] = detector.getFrequency();
    doc["noiseFloorLevel"] = detector.getNoiseFloorLevel();
    doc["outdoorMode"] = detector.getOutdoorMode();
    doc["watchdogThreshold"] = detector.getWatchdogThreshold();
    doc["minimumNumberOfLightning"] = detector.getMinimumNumberOfLightning();
    doc["spikeRejection"] = detector.getSpikeRejection();
    doc["outdoorMode"] = detector.getOutdoorMode();
    doc["statusLed"] = cfgMgr.config.ledEnabled;
    doc["blueBrightness"] = cfgMgr.config.blueBrightness;
    doc["disturberBrightness"] = cfgMgr.config.disturberBrightness;
    sendJsonResponse(doc);
}

void handleUpdate() {
    if (authenticated()) {
        bool needsClearing = false;

        if (server.hasArg("watchdogThreshold")) {
            long val = String(server.arg("watchdogThreshold")).toInt();
            if (val >= 0 && val <= 10) {
                cfgMgr.config.watchdogThreshold = val;
                detector.setWatchdogThreshold(val);
                needsClearing = true;
            }
        }

        if (server.hasArg("minimumNumberOfLightning")) {
            long val = String(server.arg("minimumNumberOfLightning")).toInt();
            if (val == 1 || val == 5 || val == 9 || val == 16) {
                cfgMgr.config.minimumNumberOfLightning = val;
                detector.setMinimumNumberOfLightning(val);
            }
        }

        if (server.hasArg("spikeRejection")) {
            long val = String(server.arg("spikeRejection")).toInt();
            if (val >= 0 && val <= 11) {
                cfgMgr.config.spikeRejection = val;
                detector.setSpikeRejection(val);
                needsClearing = true;
            }
        }

        if (server.hasArg("outdoorMode")) {
            bool val = String(server.arg("outdoorMode")) == "true";
            cfgMgr.config.outdoorMode = val;
            detector.setOutdoorMode(val);
            needsClearing = true;
        }

        if (server.hasArg("statusLed")) {
            cfgMgr.config.ledEnabled = String(server.arg("statusLed")) == "true";
        }

        if (server.hasArg("blueBrightness")) {
            long val = String(server.arg("blueBrightness")).toInt();
            if (val >= 0 && val <= 255) {
                cfgMgr.config.blueBrightness = val;
            }
        }

        if (server.hasArg("disturberBrightness")) {
            long val = String(server.arg("disturberBrightness")).toInt();
            if (val >= 0 && val <= 255) {
                cfgMgr.config.disturberBrightness = val;
            }
        }

        cfgMgr.commit();
        handleSettings();

        if (needsClearing) {
            // clear detector statistics after changing the detector config
            detector.clearStatistics();
        }
    }
}

void handleCalibrate() {
    if (authenticated()) {
        unsigned int oldColor = currentColor;
        color(COLOR_CALIBRATING);
        StaticJsonDocument<200> doc;
        doc["tuning"] = detector.calibrate();
        sendJsonResponse(doc);
        color(oldColor);
    }
}

void handleClear() {
    if (authenticated()) {
        detector.clearDetections();
        server.send(200, "text/plain", "OK");
    }
}

void handleReset() {
    if (authenticated()) {
        detector.reset();
        handleCalibrate();
        setupDetector();
        detector.clearStatistics();
    }
}

void sendMqttStatus() {
    DynamicJsonDocument doc(8192);
    String json;

    Lightning lightning;
    if (detector.getLastLightningDetection(0, lightning)) {
        doc["energy"] = lightning.energy;
        if (lightning.distance < 0x3F) {
            doc["distance"] = lightning.distance;
        } else {
            doc["distance"] = (char*) NULL;
        }
    } else {
        doc["energy"] = (char*) NULL;
        doc["distance"] = (char*) NULL;
    }

    doc["tuning"] = detector.getFrequency();
    doc["noiseFloorLevel"] = detector.getNoiseFloorLevel();
    doc["disturbersPerMinute"] = detector.getDisturbersPerMinute();
    doc["watchdogThreshold"] = detector.getWatchdogThreshold();
    doc["wifiSignalStrength"] = WiFi.RSSI();

    serializeJson(doc, json);
    if (!client.publish(MY_MQTT_TOPIC, json.c_str(), MY_MQTT_RETAIN)) {
        Serial.print("Failed to send MQTT message, rc=");
        Serial.println(client.state());
    }
}

void setupDetector() {
    detector.setOutdoorMode(cfgMgr.config.outdoorMode);
    detector.setWatchdogThreshold(cfgMgr.config.watchdogThreshold);
    detector.setMinimumNumberOfLightning(cfgMgr.config.minimumNumberOfLightning);
    detector.setSpikeRejection(cfgMgr.config.spikeRejection);
}

void color(unsigned int color) {
    if (color != currentColor) {
        neopixel.fill(color);
        neopixel.show();
        currentColor = color;
    }
}

inline int limit(int v) {
    return v <= 255 ? (v >= 0 ? v : 0): 255;
}

void updateColor(unsigned long now) {
    if (!connected) {
        color(now % 1000 <= 500 ? COLOR_CONNECTING : COLOR_BLACK);
        return;
    }

    if (!cfgMgr.config.ledEnabled) {
        color(COLOR_BLACK);
        return;
    }

    // Calculate blue color (noise floor level)
    int blue = 0;
    if (detector.isNoiseFloorLevelOutOfRange()) {
        blue = now % 1000 <= 500 ? (cfgMgr.config.blueBrightness > 128 ? cfgMgr.config.blueBrightness : 128) : 0;
    } else {
        blue = detector.getNoiseFloorLevel() * cfgMgr.config.blueBrightness / (detector.getOutdoorMode() ? 2000 : 146);
    }

    // Calculate lightning age (white) and distance (green to red)
    long red = 0;
    long green = 0;
    long white = 0;
    if (ledLightning.time > 0 && ledLightning.distance <= 40) {
        unsigned long diff = timeDifference(now, ledLightning.time);
        long distancePast = (DISTANCE_ANIMATION_TIME + ENERGY_ANIMATION_TIME) - diff;
        long energyPast = ENERGY_ANIMATION_TIME - diff;
        if (energyPast >= 0) {
            white = ((     ledLightning.energy  ) * energyPast   * 255) / (300000 * ENERGY_ANIMATION_TIME);
            blue = 0;
        } else if (distancePast >= 0) {
            green = ((     ledLightning.distance) * distancePast * 255) / (40 * DISTANCE_ANIMATION_TIME);
            red   = ((40 - ledLightning.distance) * distancePast * 255) / (40 * DISTANCE_ANIMATION_TIME);
            long newblue = ((long) blue) * diff / (DISTANCE_ANIMATION_TIME + ENERGY_ANIMATION_TIME);
            if (newblue < blue) {
                blue = newblue;
            }
        }
    }

    // Calculate last disturber fade
    unsigned long lastDisturber = detector.getLastDisturber();
    unsigned long disturberDiff = timeDifference(now, lastDisturber);
    if (cfgMgr.config.disturberBrightness > 0 && lastDisturber != 0 && disturberDiff <= DISTURBER_ANIMATION_TIME) {
        red = (cfgMgr.config.disturberBrightness * (DISTURBER_ANIMATION_TIME - disturberDiff)) / DISTURBER_ANIMATION_TIME;
    }

    color(    (limit(white) & 0xFF) << 24
            | (limit(red  ) & 0xFF) << 16
            | (limit(green) & 0xFF) << 8
            | (limit(blue ) & 0xFF));
}

void setup() {
    Serial.begin(115200);
    Serial.println("");

    cfgMgr.begin();

    detector.begin();

    neopixel.begin();
    neopixel.setBrightness(255);

    // Init detector
    color(COLOR_CALIBRATING);
    Serial.println("Calibrating antenna...");
    detector.reset();
    unsigned int freq = detector.calibrate();
    Serial.print("Calibrated antenna frequency: ");
    Serial.print(freq);
    Serial.println(" Hz");
    color(COLOR_BLACK);

    // Set up the detector
    setupDetector();

    // Start WiFi
    WiFi.setSleepMode(WIFI_NONE_SLEEP);
    WiFi.mode(WIFI_STA);
    connectedEventHandler = WiFi.onStationModeConnected([](const WiFiEventStationModeConnected& event) {
        Serial.print("WiFi connected to: ");
        Serial.println(WiFi.SSID());
        Serial.print("MAC: ");
        Serial.println(WiFi.macAddress());
    });
    gotIpEventHandler = WiFi.onStationModeGotIP([](const WiFiEventStationModeGotIP& event) {
        Serial.print("IP address: ");
        Serial.println(WiFi.localIP());
        server.begin();
        Serial.print("Server is listening on port: ");
        Serial.println(PORT);
        connected = true;
    });
    disconnectedEventHandler = WiFi.onStationModeDisconnected([](const WiFiEventStationModeDisconnected& event) {
        connected = false;
        Serial.println("WiFi connection lost. Reconnecting...");
        WiFi.begin(MY_SSID, MY_PSK);
    });
    WiFi.begin(MY_SSID, MY_PSK);

    // Start MDNS
    if (MDNS.begin(MY_MDNS_NAME)) {
        Serial.println("MDNS responder started");
        MDNS.addService("http", "tcp", PORT);
    }

    // Start server
    server.on("/status", handleStatus);
    server.on("/settings", handleSettings);
    server.on("/update", handleUpdate);
    server.on("/calibrate", handleCalibrate);
    server.on("/clear", handleClear);
    server.on("/reset", handleReset);
    server.onNotFound([]() {
        server.send(404, "text/plain", server.uri() + ": not found\n");
    });
    const char * headerkeys[] = { "X-API-Key" };
    server.collectHeaders(headerkeys, sizeof(headerkeys) / sizeof(char*));
}

void loop() {
    const unsigned long now = millis();

    if (connected) {
        server.handleClient();
        MDNS.update();

        #ifdef MY_MQTT_ENABLED
        if (!client.loop() && timeDifference(now, beforeMqttConnection) > 1000) {
            beforeMqttConnection = now;
            if (client.connect(MY_MQTT_CLIENT_ID, MY_MQTT_USER, MY_MQTT_PASSWORD)) {
                Serial.println("Successfully connected to MQTT server");
            } else {
                Serial.print("Connection to MQTT server failed, rc=");
                Serial.println(client.state());
            }
        }
        #endif
    }

    if (detector.update()) {
        if (!detector.getLastLightningDetection(0, ledLightning)) {
            ledLightning.time = 0;
        }
        #ifdef MY_MQTT_ENABLED
        if (connected && client.connected()) {
            sendMqttStatus();
        }
        #endif
    }

    if (timeDifference(now, beforeAnimation) > 50) {
        beforeAnimation = now;
        updateColor(now);
    }
}

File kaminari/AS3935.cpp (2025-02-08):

/*
 * Kaminari
 *
 * Copyright (C) 2020 Richard "Shred" Körber
 *   https://codeberg.org/shred/kaminari
 *
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
 * This program is distributed in the hope that it will be useful,
 * but WITHOUT ANY WARRANTY; without even the implied warranty of
 * MERCHANTABILITY or FITNESS FOR A PARTICULAR PURPOSE.  See the
 * GNU General Public License for more details.
 */

#include <Arduino.h>
#include <SPI.h>

#include "AS3935.h"

#define BITRATE 1400000         // max bitrate is 2 MHz, should not be dividable by 500 kHz
#define NOISE_LEVEL_RAISE_DELAY      60000  // Delay before noise level can be raised again
#define NOISE_LEVEL_REDUCTION_DELAY 600000  // Delay before noise reduction is lowered again

const int outdoorLevels[]   = { 390,  630,  860, 1100, 1140, 1570, 1800, 2000 };
const int indoorLevels[]    = {  28,   45,   62,   78,   95,  112,  130,  146 };
const int minNumLightning[] = { 1, 5, 9, 16 };

volatile static unsigned long counter = 0;       // Internal counter

ICACHE_RAM_ATTR static void counterISR() {
    counter++;
}


AS3935::AS3935(int csPin, int intPin) {
    unsigned long now = millis();
    this->csPin = csPin;
    this->intPin = intPin;
    this->frequency = 0;
    this->lastNoiseLevelChange = now;
    this->lastNoiseLevelRaise = now;
    this->noiseLevelBalance = 0;
    this->currentNoiseFloorLevel = -1;
    this->currentOutdoorMode = false;
    this->noiseFloorLevelOutOfRange = false;
    this->disturberCounterStart = now;
    this->disturberCounter = 0;
    this->lastDisturber = 0;

    clearDetections();
}

void AS3935::begin() {
    SPI.begin();

    pinMode(this->csPin, OUTPUT);
    digitalWrite(this->csPin, HIGH);

    pinMode(this->intPin, INPUT);

    attachInterrupt(digitalPinToInterrupt(this->intPin), counterISR, RISING);
}

void AS3935::end() {
    detachInterrupt(digitalPinToInterrupt(this->intPin));
    digitalWrite(this->csPin, HIGH);
    SPI.end();
}

bool AS3935::update() {
    bool hasChanged = false;
    unsigned long now = millis();

    if (counter > 0) {
        counter = 0;

        open();
        delay(2);       // wait 2 ms before reading the interrupt register!
        char interrupt = spiRead(0x03) & 0x0F;
        close();

        if ((interrupt & 0x01) != 0 && (now - lastNoiseLevelRaise) > NOISE_LEVEL_RAISE_DELAY) {
            // Noise level too high
            lastNoiseLevelChange = now;
            lastNoiseLevelRaise = now;
            noiseLevelBalance++;
            if (noiseLevelBalance > 1) {
                noiseLevelBalance--;
                if (raiseNoiseFloorLevel()) {
                    noiseFloorLevelOutOfRange = false;
                    hasChanged = true;
                } else {
                    noiseFloorLevelOutOfRange = true;
                }
            }
        }

        if ((interrupt & 0x04) != 0) {
            // Disturber detected
            disturberCounter++;
            this->lastDisturber = now;
        }

        if ((interrupt & 0x08) != 0) {
            // Lightning detected
            for (int ix = sizeof(lastLightningDetections) / sizeof(Lightning) - 1; ix > 0; ix--) {
                lastLightningDetections[ix] = lastLightningDetections[ix - 1];
            }
            lastLightningDetections[0].time = now;
            lastLightningDetections[0].energy = getEnergy();
            lastLightningDetections[0].distance = getEstimatedDistance();
            hasChanged = true;
        }
    }

    // Try to reduce the noise level again
    if ((now - lastNoiseLevelChange) > NOISE_LEVEL_REDUCTION_DELAY) {
        lastNoiseLevelChange = now;
        noiseLevelBalance--;
        if (noiseLevelBalance < -1) {
            noiseLevelBalance++;
            if (noiseFloorLevelOutOfRange) {
                noiseFloorLevelOutOfRange = false;
            } else {
                reduceNoiseFloorLevel();
                hasChanged = true;
            }
        }
    }

    return hasChanged;
}

void AS3935::powerDown() {
    open();
    spiWrite(0x00, 0x25);
    close();
}

void AS3935::reset() {
    open();
    spiWrite(0x3C, 0x96);       // PRESET_DEFAULT: Reset all registers
    delay(2);
    spiRead(0x03);              // Clear interrupts
    counter = 0;
    close();
}

unsigned long AS3935::calibrate(unsigned long freq) {
    open();
    if (spiRead(0x00) & 0x37 == 0x00) {
        Serial.println("The AS3935 does not respond. Please check your SPI wiring!");
    }

    spiWrite(0x03, 0xC0);       // Set division ratio to 128

    byte mask = 0x00;
    unsigned long actualFreq;
    unsigned long bestFreq;
    byte testMask;
    byte bestMask;
    long bestDiff = 1000000;
    long currentDiff;
    for (int bit = 3; bit >= 0; bit--) {
        testMask = mask | (1 << bit);
        spiWrite(0x08, 0x80 | testMask);
        delay(50);             // Let oscillator settle...

        // Measure frequency for 500ms, repeat if not plausible
        do {
            counter = 0;
            delay(500);
            actualFreq = counter * 128 * 2;
            currentDiff = actualFreq - freq;
            if (currentDiff < 0) {
                currentDiff = -currentDiff;
            }
        } while (actualFreq > 0 && currentDiff > 50000);

        // Remember the best frequency and corresponding bit mask
        if (currentDiff < bestDiff) {
            bestDiff = currentDiff;
            bestFreq = actualFreq;
            bestMask = testMask;
            if (bestDiff < 500) {
                break;
            }
        }

        // Test the next bit
        if (actualFreq/1000 > freq/1000) {
            mask = testMask;
        }
    }

    if (bestFreq == 0) {
        Serial.println("No interrupt was detected during calibration. Please check your IRQ wiring!");
    } else if (bestFreq < 483092 || bestFreq > 517500) {
        Serial.println("Warning: calibrated frequency is out of tolerance range.");
    }

    this->frequency = bestFreq;

    spiWrite(0x08, bestMask);       // Set the target frequency, disable DISP_LCO output
    delay(50);                      // Let everything settle for a while
    spiWrite(0x3D, 0x96);           // CALIB_RCO: Now calibrate the RCOs
    spiWrite(0x08, 0x20 | bestMask); // Enable TRCO for calibration
    delay(2);                       // Wait another 2 ms
    spiWrite(0x08, bestMask);       // Disable TRCO again
    delay(50);                      // Let everything settle again
    spiRead(0x03);                  // Clear interrupts
    counter = 0;

    close();
    return bestFreq;
}

bool AS3935::raiseNoiseFloorLevel() {
    bool success = false;
    open();
    byte current = spiRead(0x01);
    int value = (current >> 4) & 0x07;
    value++;
    if (value <= 7) {
        spiWrite(0x01, (current & 0x8F) | value << 4);
        success = true;
    }
    updateNoiseFloorLevel();
    close();
    return success;
}
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

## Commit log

2020-04-25 First release
    [base.scad, clip.scad, holder.scad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]
2020-04-28 Add out-of-range detection for noise floor level
    Before that, out-of-range was assumed when the highest possible noise floor level was used. Now out-of-range is reported when the highest noise floor level is used, but there are still disturbers being detected.
    [AS3935.cpp, kaminari.ino]
2020-06-08 Change noise floor level calibration algorithm
    The old algorithm was too conservative. It raised the noise floor level too high, so no lightnings could be detected. The new algorithm defines an acceptable number of noise error events per 10 seconds, which is also configurable.
    [AS3935.cpp, Config.cpp, kaminari.ino]
2020-06-30 Revert "Change noise floor level calibration algorithm"
    This reverts commit a146501096a22ae1334e7eaa818d7f416537524f.
    [AS3935.cpp, Config.cpp, kaminari.ino]
2020-06-30 Remove 3D printed case
    The case was designed with the detector and the ESP being too close together, so the detector was permanently disturbed by the ESP. As result, the detector was unable to detect even close lightnings. The case is nice, but flawed, and was thus removed.
    [base.scad, clip.scad, holder.scad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]
2020-07-02 Add a reset endpoint
    [kaminari.ino]
2020-07-22 Fix build error (issue #2)
    [kaminari.ino]
2020-08-15 Add note about required space between WiFi antenna and detector coil
2021-03-29 Log MQTT publishing errors
    [kaminari.ino]
2021-05-13 Enhance and speed up antenna calibration
    - Only the closest match >500kHz was found before. The result was that
    e.g. 501342 Hz was preferred over 499998 Hz. Now the bitmask that is
    actually closest to 500kHz is found, giving a much better calibration
    result.
    - The frequency measurement is repeated if the result was not plausible.
    - Frequency is taken for 500ms instead of 1s, shortening the calibration
    time by about 50%.
    - Calibration is stopped if an optimal result was already found.
    - Added short delays to let oscillator settle before measurement.
    [AS3935.cpp]
2021-06-05 Fix sending of MQTT status
    [kaminari.ino]
2022-02-01 Remove Auto Watchdog Threshold
    Reason: The detector chip seems to be confused by too many changes to
    the watchdog configuration. Turning off autoWatchdogMode gave a much
    better overall performance. For this reason, the automatic watchdog
    threshold has been completely removed.
    This update resets the configuration. After updating, the configs need
    to be set again.
    [AS3935.cpp, Config.cpp, kaminari.ino]
2023-06-28 No update if noise floor level is unchanged (fixes #8)
    [AS3935.cpp]
